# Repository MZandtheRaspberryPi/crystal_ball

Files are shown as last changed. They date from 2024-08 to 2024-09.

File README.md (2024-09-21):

# crystal_ball
A fun electronics project to make a witch's staff that mounts to a cane. I made the initial version in 2 (pretty frantic) days before a music festival. Then I took a couple weeks after to polish a version 2!

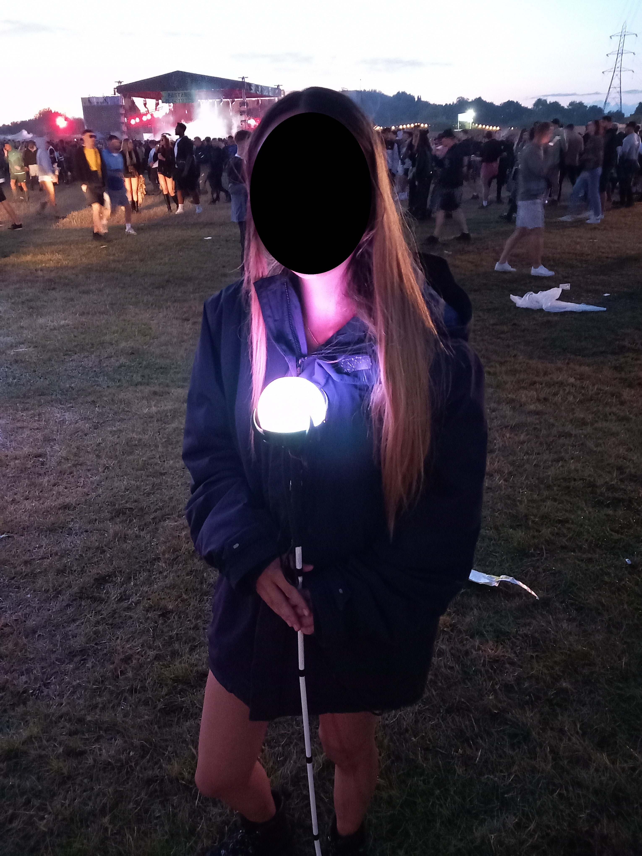
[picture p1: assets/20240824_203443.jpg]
at_festival
  
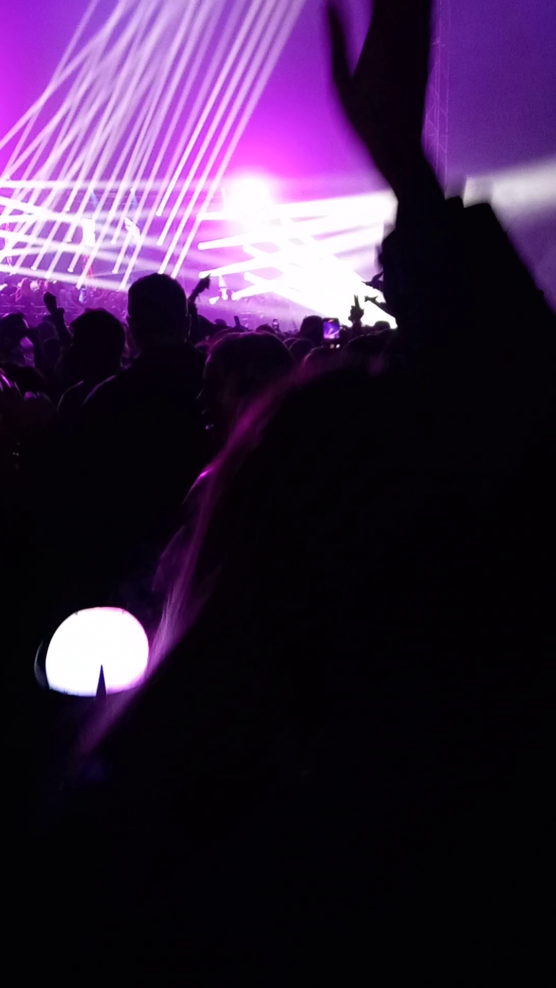
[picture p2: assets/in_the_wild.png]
in_the_wild
  

# The Design
I knew I wanted to mount to the cane using brackets that clamped to the cane. I pictured a witch or wizard's staff with a colourful orb of changing colours on top of the staff. From here, I made some initial sketches.  
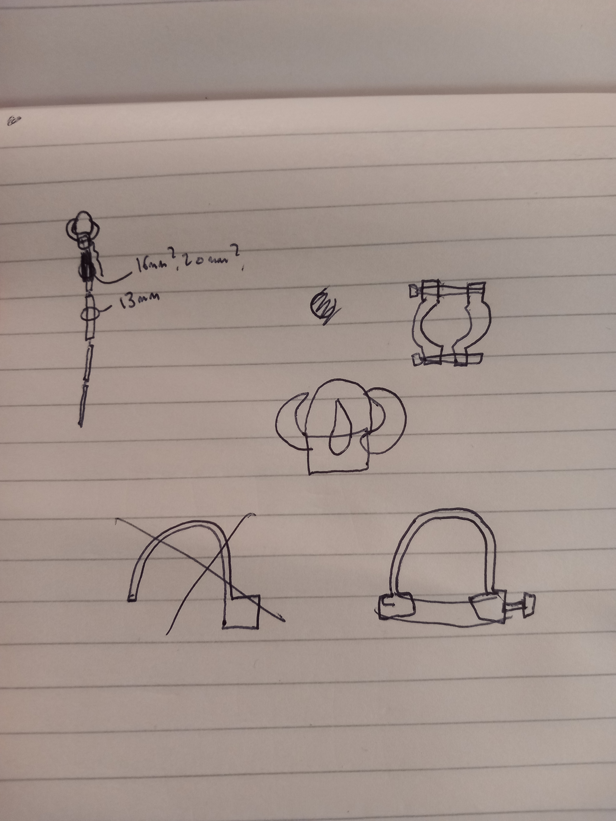
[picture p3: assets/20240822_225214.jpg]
sketch
  

My first version looked like the below, but this had some trouble mounting to the cane because the mounts were too close to the crystal ball.  
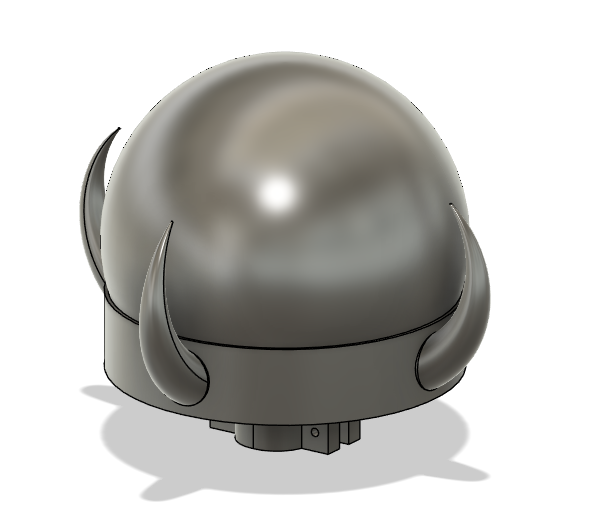
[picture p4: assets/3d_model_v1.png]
3d-model-v1
  

After a lot of 3d-modelling and many failed prints, I ended up with the below:
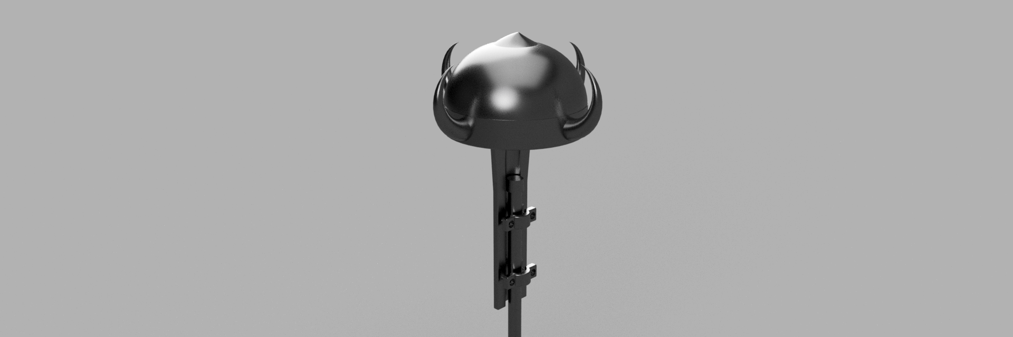
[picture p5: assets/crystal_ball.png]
3d-model-v2
  

Some of my considerations in the design were how to structure the dome. I wanted it to be super thin, ideally one nozzle perimeter of 0.4mm, so that light would get through. But, such a thin part is very tricky to print, especially because I wanted the top to be pretty flat meaning supports would typically be used. You can see how many failed dome iterations I had before I got some working below. I ended up printing it at 0.05mm layer height, with extra perimeters if needed and extra perimeter on overhands enabled in prusa-slicer.  
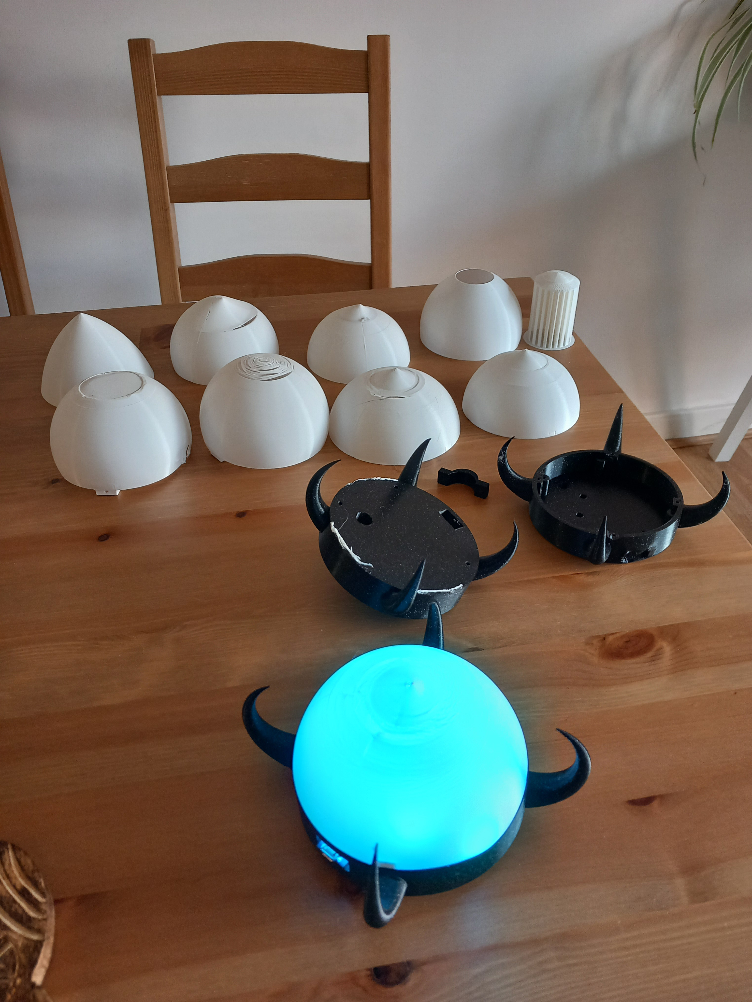
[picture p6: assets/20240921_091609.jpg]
failed_prints


You can see a .gif of me the finished 3d-model being created step by step thanks to a cool feature in fusion 360.
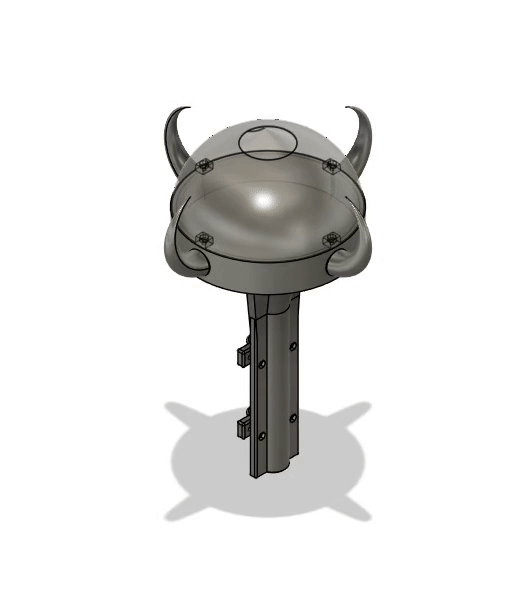
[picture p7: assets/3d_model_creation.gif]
creation_gif
  

The 3d-models can be found in the assets 3d-models subfolder.  

# hardware
I was pretty proud that for version 1, I used parts that I had lying around, namely some Adafruit through-hole Neopixels and a Pi Pico W. It wasn't pretty but it worked.  
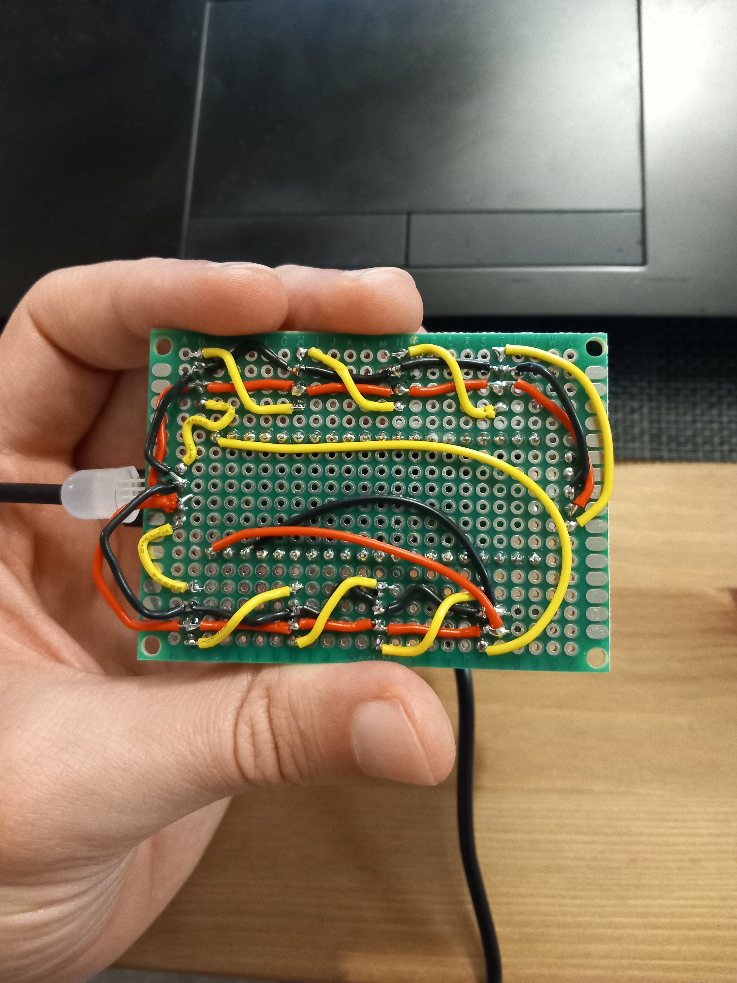
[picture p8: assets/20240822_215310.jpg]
hardware
  
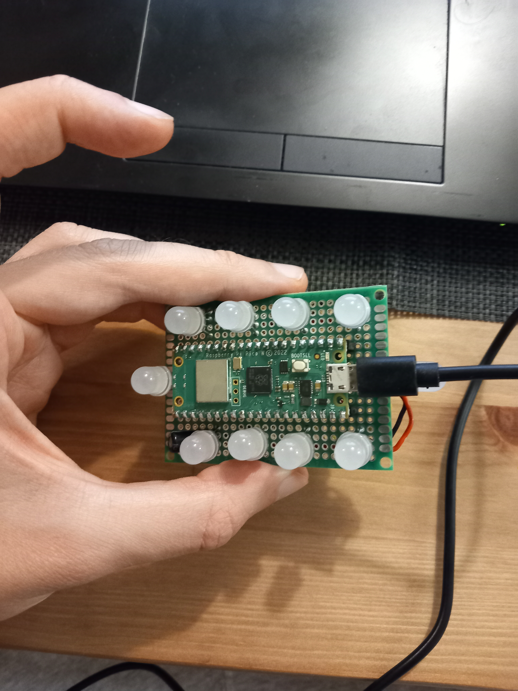
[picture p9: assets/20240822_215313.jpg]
hardware2
  

This version didn't have a battery, so a cable went out through the bottom of the orb and to a portable USB power bank inside of a pocket. While dancing it became evident this was a terrible idea, and we needed a battery inside of the orb. The cable would get snagged, pull out, and just generally made me nervous.

To integrate a battery, I used an Adafruit feather specifically the ESP32 v2 feather. I used a 2000mAh Lipo. The feather made it easy to manage the battery, and I was already using circuit python so the feather had support for that and porting the software to the new hardware was easy. I was able to re-use the perf-board that I had made the neopixel circuit on.  

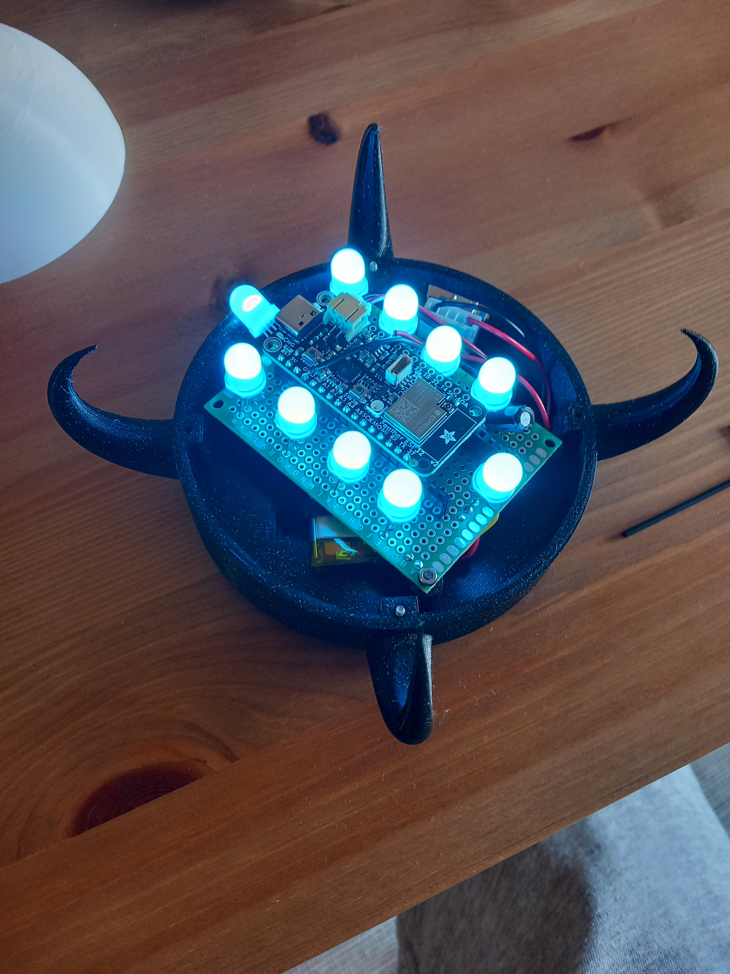
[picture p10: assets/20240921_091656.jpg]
hardware_v2


# code
I used Adafruit's circuit python, neopixel, and http_server libraries. I knew that I wanted various light animations and to be able to control the brightness and light modes while out and about. When dancing in a dark tent, full brightness is annoying to others around us, hence the need to control brightness. To accomplish this, I had the microcontroller broadcast a WLAN network in AP mode and hosted a webserver that served a webapp to control everything.  

The web app looked like this:  
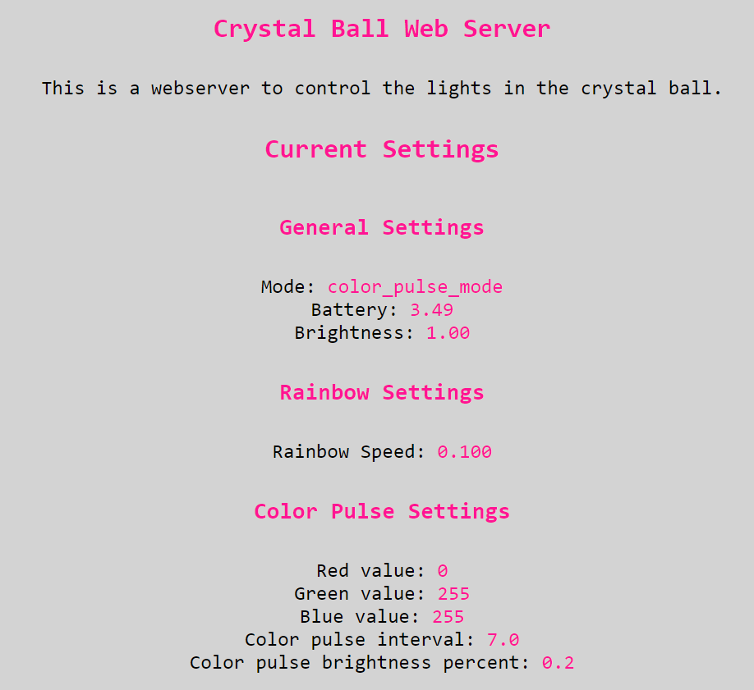
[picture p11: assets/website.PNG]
website

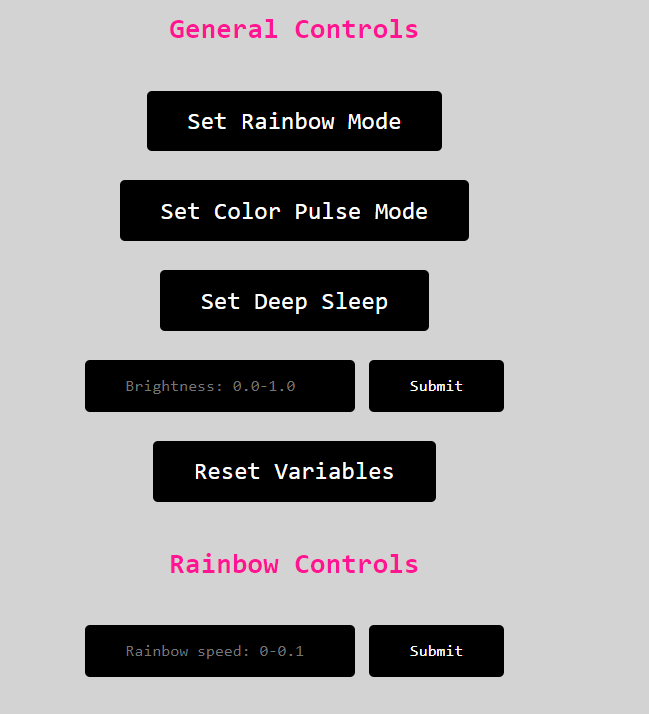
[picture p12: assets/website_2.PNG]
website

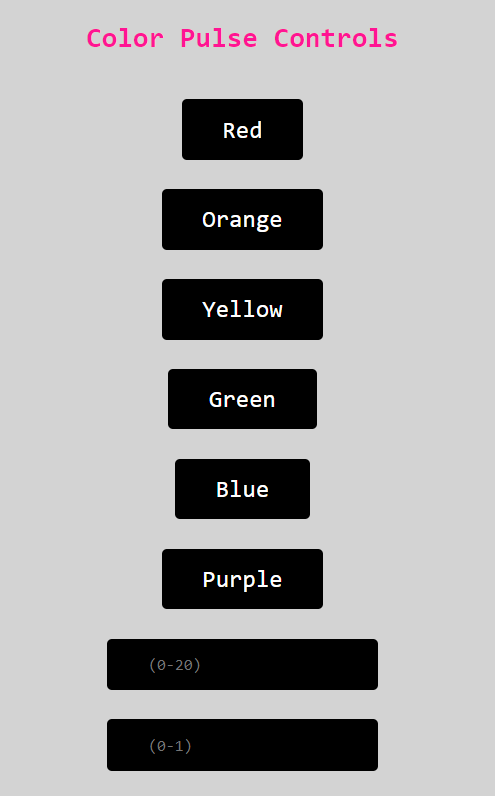
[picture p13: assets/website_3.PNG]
website

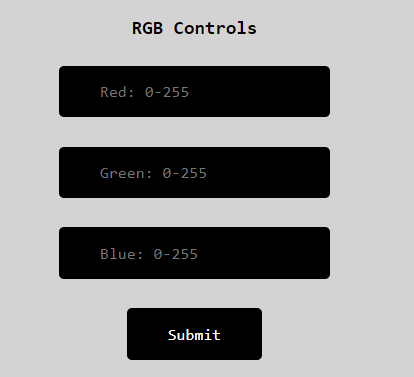
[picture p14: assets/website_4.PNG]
website


For the software, Adafruit's learning ecosystem (like  [this](https://learn.adafruit.com/pico-w-http-server-with-circuitpython/create-your-settings-toml-file)) and circuit python's documentation made it a lovely first experience with that stack. More code details are in the code subfolder and source code is there as well.  

# assembly

This project had a lot of moving pieces, from design to hardware to software. Integrating it all into a final product was non-trivial but I was proud of the end-result.

Version 1 didn't have a battery, but was still cool. I didn't get a complete dome printed in time due to the issues I mentioned earlier, so I ended up welding a plastic disc to the top of a dome that had failed printing. Most of the pieces fit together with captive nuts and M2 mechanical screws. A picture is below and you can see a video demo [here](https://youtube.com/shorts/bqeQ5W-EpfM) and [here](https://youtube.com/shorts/Z6r9HBsY354).
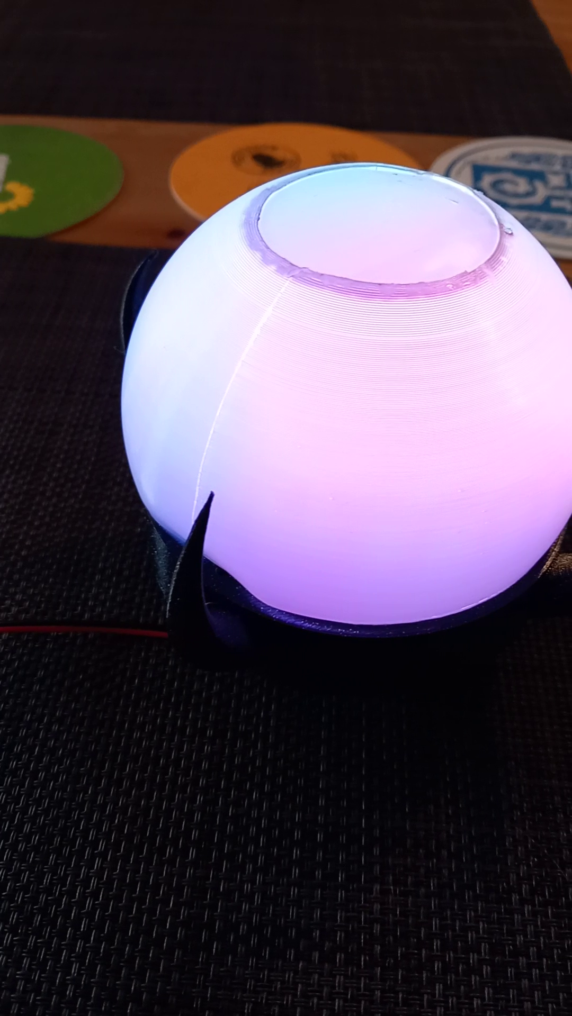
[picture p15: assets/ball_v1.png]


Version 2 fixed some design issues with version 1 and introduced a battery, plus some more software features. It's not perfect--for example mounting it to and from the cane requires finessing some M2 screws and hex nuts that have a tendency to jump out of the hand and hide forever under the couch--but it is something I am proud of. You can see a picture below and a video [here](https://youtube.com/shorts/kJiOJtX-Ke8).
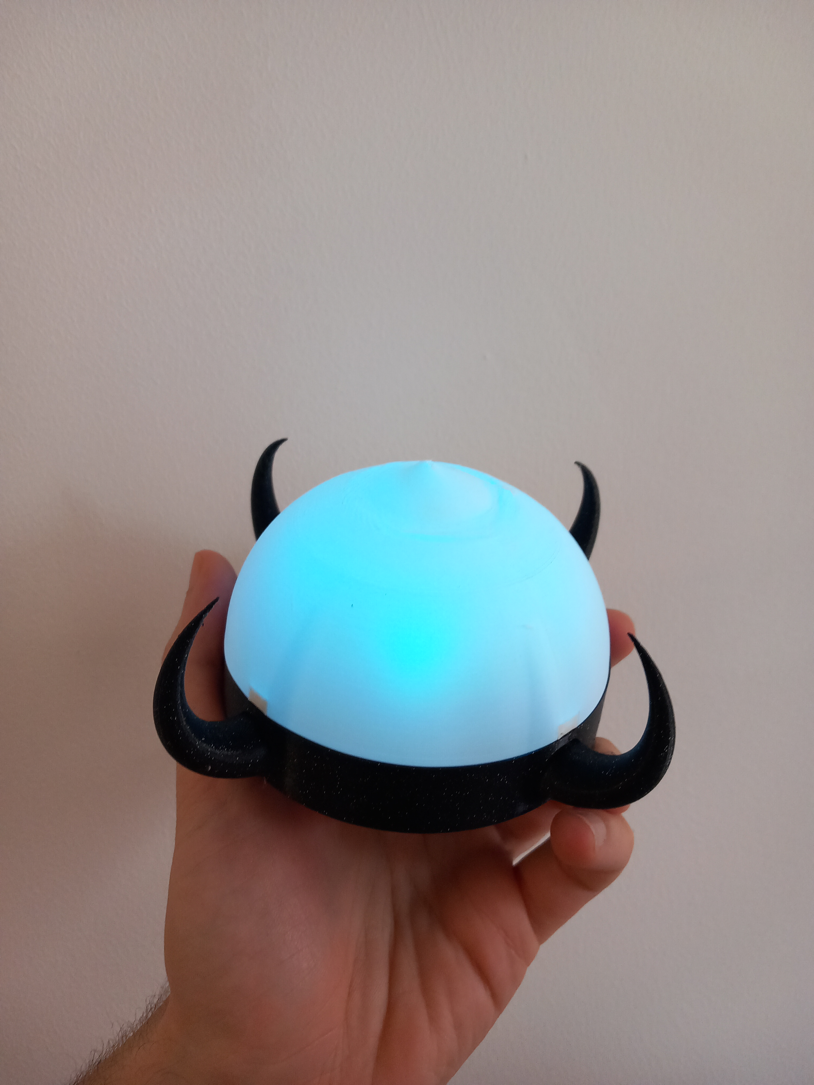
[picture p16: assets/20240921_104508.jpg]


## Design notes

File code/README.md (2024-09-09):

# code

The code uses circuit python. For hardware we use an ESP32 V2 Feather from Adafruit.

Installing circuit python is a bit of a pain, but [this](https://learn.adafruit.com/circuitpython-with-esp32-quick-start/installing-circuitpython) guide helps. I used [esptool](https://docs.espressif.com/projects/esptool/en/latest/esp32/index.html#quick-start) to flash circuit python, installed [thonny](https://thonny.org/) and pointed it to my circuit python port as the interpreter. Used thonny to copy the the adafruit libraries for `neopixel` and `adafruit_httpserver`. From there I used thonny to edit the`settings.toml to include wlan details (example below). Then I used thonny to copy my code across.

```
(virtual_env) D:\ziegl\git\crystal_ball>esptool.py --port COM15 erase_flash
esptool.py v4.7.0
Serial port COM15
Connecting.......
Detecting chip type... Unsupported detection protocol, switching and trying again...
Connecting....
Detecting chip type... ESP32
Chip is ESP32-PICO-V3-02 (revision v3.0)
Features: WiFi, BT, Dual Core, 240MHz, Embedded Flash, Embedded PSRAM, VRef calibration in efuse, Coding Scheme None
Crystal is 40MHz
MAC: e8:9f:6d:30:66:6c
Uploading stub...
Running stub...
Stub running...
Erasing flash (this may take a while)...
Chip erase completed successfully in 20.7s
Hard resetting via RTS pin...
```

```
(virtual_env) D:\ziegl\git\crystal_ball>esptool.py --port COM15 write_flash -z 0x0 D:\ziegl\Downloads\adafruit-circuitpython-adafruit_feather_esp32_v2-en_US-9.1.3.bin
esptool.py v4.7.0
Serial port COM15
Connecting....
Detecting chip type... Unsupported detection protocol, switching and trying again...
Connecting....
Detecting chip type... ESP32
Chip is ESP32-PICO-V3-02 (revision v3.0)
Features: WiFi, BT, Dual Core, 240MHz, Embedded Flash, Embedded PSRAM, VRef calibration in efuse, Coding Scheme None
Crystal is 40MHz
MAC: e8:9f:6d:30:66:6c
Uploading stub...
Running stub...
Stub running...
Configuring flash size...
Flash will be erased from 0x00000000 to 0x001b4fff...
Compressed 1789264 bytes to 1174886...
Wrote 1789264 bytes (1174886 compressed) at 0x00000000 in 103.3 seconds (effective 138.6 kbit/s)...
Hash of data verified.

Leaving...
Hard resetting via RTS pin...
```

Example settings.toml
```
SSID_NAME="crystal_ball"
WLAN_PASS="change_me"
```

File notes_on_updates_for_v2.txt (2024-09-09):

Notes on Updates for V2
3d design
Mount the orb lower down on the cane, more stable, directly onto cane not onto ribbon. Perhaps 2/4 mounting points?
multiple mounts for the bowl so it doesn't make noise/shift around. Consider inserting into the mount with a channel for bowl and mount points by 1mm for light?
for the pcb, put hex mounts on the botton of base, screw down.

hardware
move to battery and 3.3v w/ adafruit feather. esp32.

software
button shouldn't refresh page or move away
make button text less verbose
make it easier to adjust colours
add in more modes

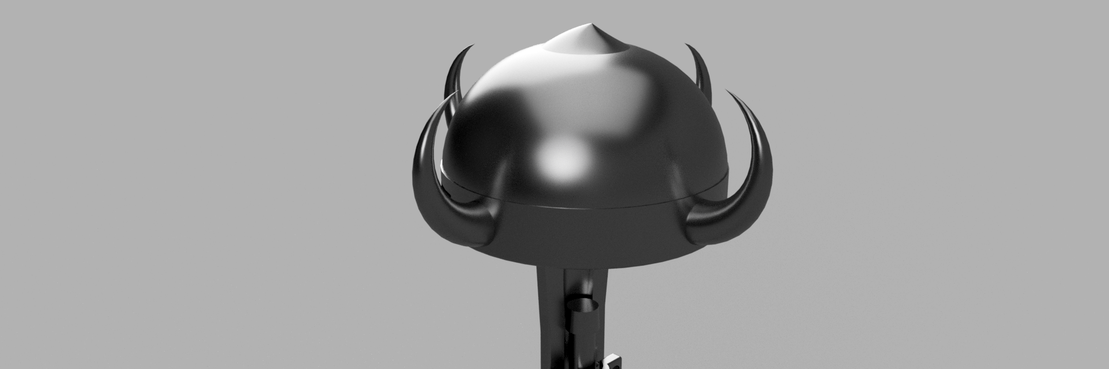
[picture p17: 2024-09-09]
assets/crystal_ball_zoomed.png

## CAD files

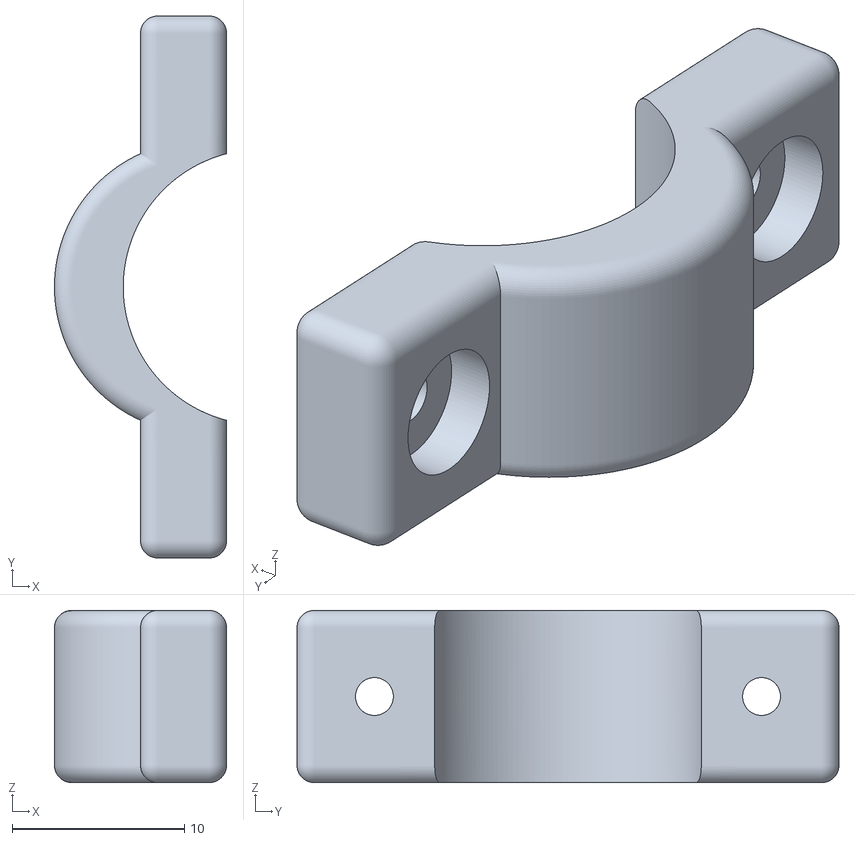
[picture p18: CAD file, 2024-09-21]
3d-models/bracket_2.stl
10.00 x 31.5 x 10.0

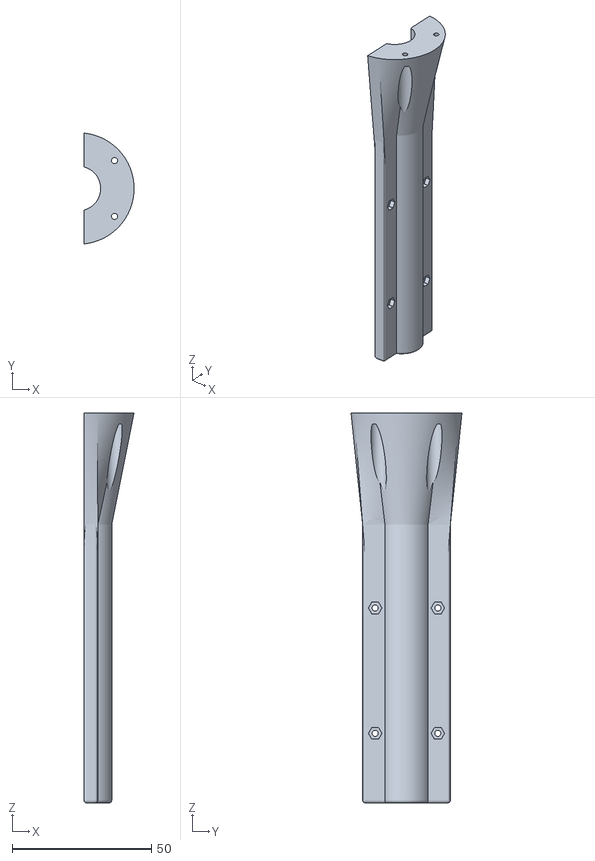
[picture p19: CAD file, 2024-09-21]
3d-models/mounting_bracket_long.stl
18.0 x 39.8 x 140.0

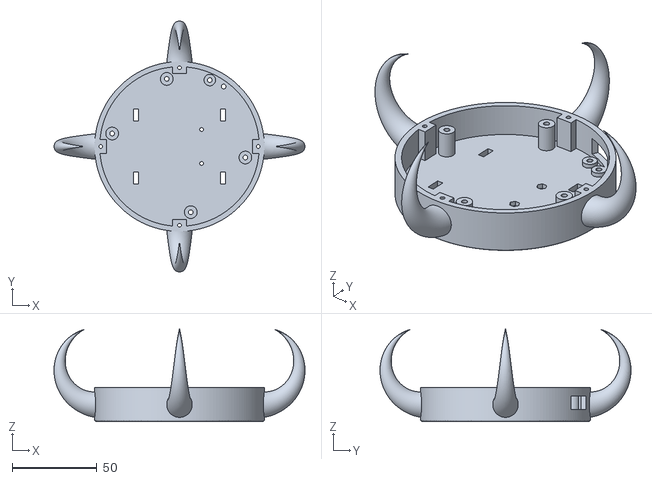
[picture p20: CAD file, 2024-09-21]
3d-models/base.stl
147.9 x 147.9 x 54.3

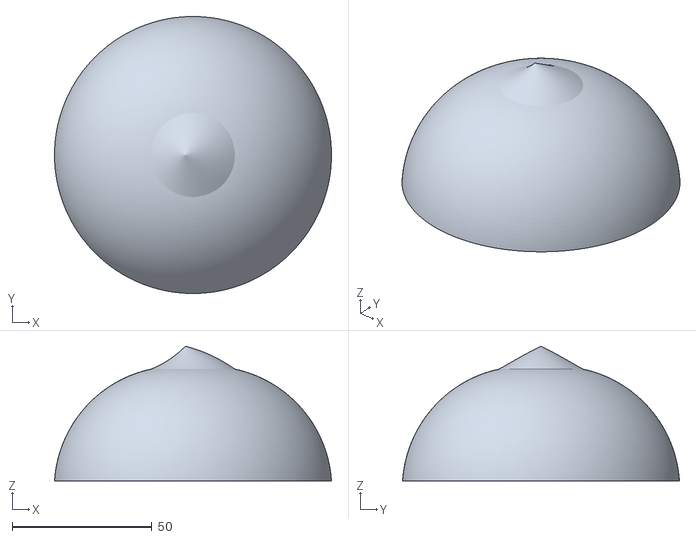
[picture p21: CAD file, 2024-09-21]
3d-models/DOME.stl
99.2 x 99.2 x 48.2

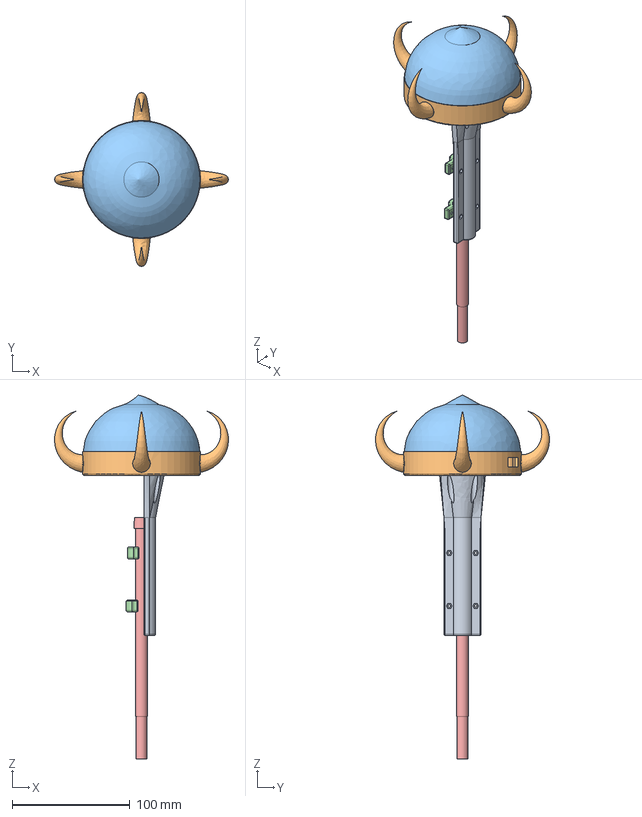
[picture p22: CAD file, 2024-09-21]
3d-models/crystal_ball v29.step
147.8 x 147.8 x 309.2 mm
cane

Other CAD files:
3d-models/bracket_1.stl
3d-models/crystal_ball v29.f3z
